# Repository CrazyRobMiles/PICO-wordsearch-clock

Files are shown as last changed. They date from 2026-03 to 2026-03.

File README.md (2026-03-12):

# PICO Wordsearch Clock

A Raspberry Pi PICO powered clock that shows the time on a 16x16 character wordsearch

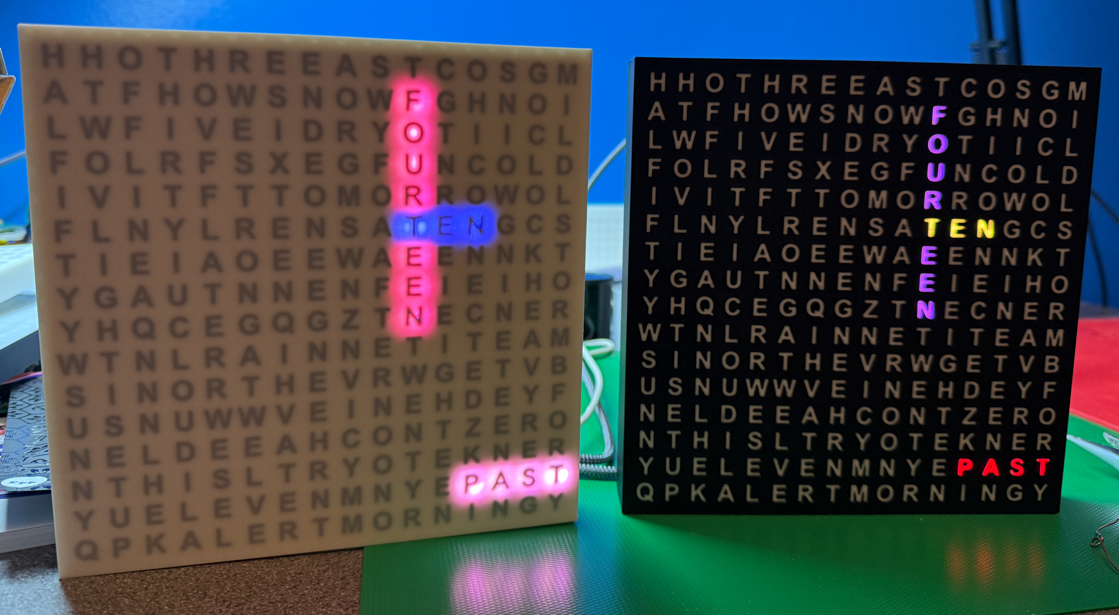
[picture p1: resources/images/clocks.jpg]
TWo wordsearch clocks, one black on white and the other white on black


There are two versions of the clock. One is an alarm clock. The same software works with both versions.

## Installing the software

**These instructions assume that you are familiar with MicroPython development for the Raspberry Pi PICO.**

The software is in the **firmware-PICO** folder. Install MicroPython on your device and then copy all the files in the **firmware-PICO** folder onto your device. You can use the Thonny program or Visual Studio Code with the Raspberry Pi plugin to do this. 

The best way to deploy the software is to use the Raspberry Pi Pico plugin for Visual Studio Code. Install the plugin and then open the **firmware-PICO** folder with Visual Studio Code **not** this repository. Plug the target PICO W into your computer, right click on any file in the file explorer and select **Upload Project to Pico** from the context menu that appears. Now you can configure the Wi-Fi. 

## Configuring the Wi-Fi

Once you have installed the software you will need to configure the Wi-Fi connection for your clock. The clock uses Wi-Fi to get the date and time. The configuration for Wi-Fi is in the **settings.json** file in the firmware folder. Use Thonny or Visual Studio Code 

```json
    "wifi": {
        "dependencies": [],
        "wifipwd1": "",
        "enabled": true,
        "retry_interval_ms": 30000,
        "wifissid1": ""
    },
```
You need to set values for **wifipwd1** and **wifissid1**. Save the file back to the device after you have edited it. Now, when your clock starts it will connect to your Wi-Fi and start displaying the time. 

### **IMPORTANT NOTE**

Your Wi-Fi settings are held in clear text inside the clock. Anyone who gains access to the clock could plug it into their computer and read the Wi-Fi settings out of it. It is good practice to create a "guest" Wi-Fi account for embedded devices so that anyone getting the credentials does not get access to all the devices on your home network. 

## Using the alarm clock

### Getting started
Plug in the clock and it should fetch the time from the internet start showing it. This will  take a few seconds to do this. The clock will not display the time until it has established a Wi-Fi connection. 

### Adjusting Brightness

Use the white buttons to adjust the brightness. One button makes the clock brighter and the other makes it darker. 

### Adjusting the alarm time

Press and hold the red button to set the alarm hour. Use the white buttons to adjust the hour value. Note that this is a 24-hour clock setting. Times after mid-day will be plus 12. In other words 2:00pm will be 14:00 hours. 

Press and hold the blue button to set the alarm minute. Use the white buttons to adjust the minute value. 

If you hold down a white button it will automatically step through the values for you. 

### Turning the alarm on and off

Press the red and blue buttons to turn the alarm on and off. The display will show yellow for off and red for the alarm on. 

### Alarm sound

If the alarm is enabled it will trigger at the set time. Press any button to cancel the alarm. 

### Alarm demonstration

To see a demonstration of the alarm display and sound, press both white buttons together. If the alarm is disabled you will hear one demo. 

# Building a clock of your own

You can find out how to build your own clock in the resources folder [here](/resources/README.md).

Have Fun!

[Rob Miles](https://www.robmiles.com/)

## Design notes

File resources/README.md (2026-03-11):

## Building a clock

You can build your own version of the clock. The simplest way to do this is to use the supplied case designs and **clockface.json** file. This will produce a clock with the wordsearch arrangement you can see above. If you want to make your own wordsearch design you can do this, but it is slightly more complex.

If you build the alarm clock you'll need to set up a MicroSD card with the sound samples to be used for the alarms. 

### Printing the case

The stl files and instructions are [here](stl/README.md).

### Building the electronics

You can find a parts list and circuit diagram [here](circuit/README.md)

### Designing your own Wordsearch

You can find out how to make your own wordsearch design [here](custom/README.md). 

## Creating your own sounds for the clock

You can find out how to create your own alarm sounds [here](sounds/README.md).

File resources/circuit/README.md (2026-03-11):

# Building the Circuit

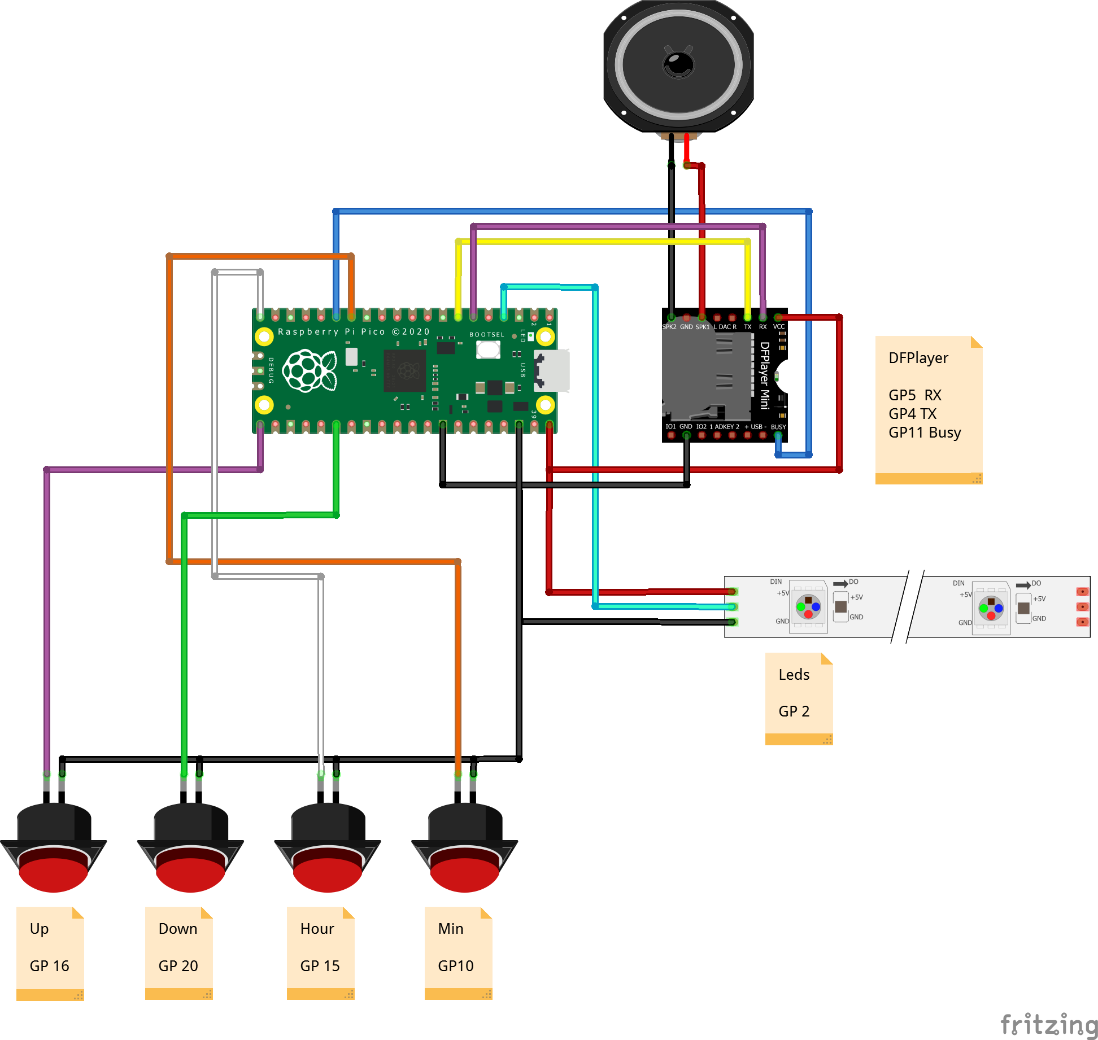
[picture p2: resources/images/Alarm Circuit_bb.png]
Circuit diagram of the clock


The diagram shows the circuit for the clock. If you are not building the alarm clock you only need these:

* Raspberry PI PICO 2 W
* 16x16 led panel with 10mm led spacing. 
* DuPont cables. The prototypes were constructed by using short DuPont male-to-male cables which were soldered into the switch connections onto the LED panel. the other male end of the cables were soldered into the PICO directly. One special cable was created which split the VBUS power connection so that the leds and the DFPlayer could be powered. 

## Alarm Clock

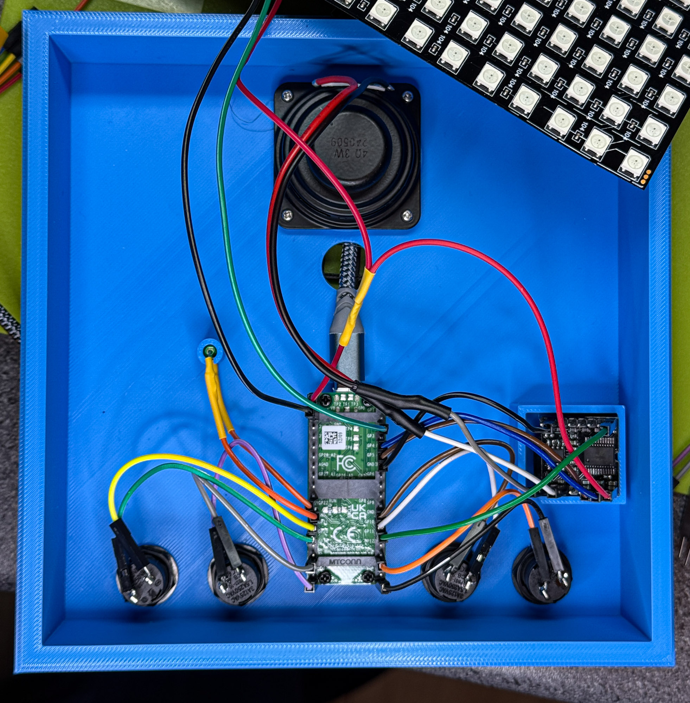
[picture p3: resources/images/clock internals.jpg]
Image of the inside of the clock showing connections


You can make a version of the clock which will sound an alarm at a set time during the day. The alarm sounds are stored on a Micro-SD card inside the clock and played by a DFPlayer device controlled by the PICO. The alarm clock uses four buttons to set the alarm. You need these extra components:

* DFPlayer - search for "DFPlayer Mini mp3" 
* Micro-SD card – between 4Gbytes and 16Gbytes work well
* Four non-latching push buttons which fit in a 13mm diameter hole
* 40mm speaker with mounting holes spaced at 32.5mm

## Design Changes

You can modify the FreeCAD program that creates the case if you wish to use differently sized components.  You can modify the **settings.json** file for the device if you want to use different pin assignments in your circuit.

[Resources Home](../README.md)

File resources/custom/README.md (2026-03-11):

# Custom Wordsearch Design

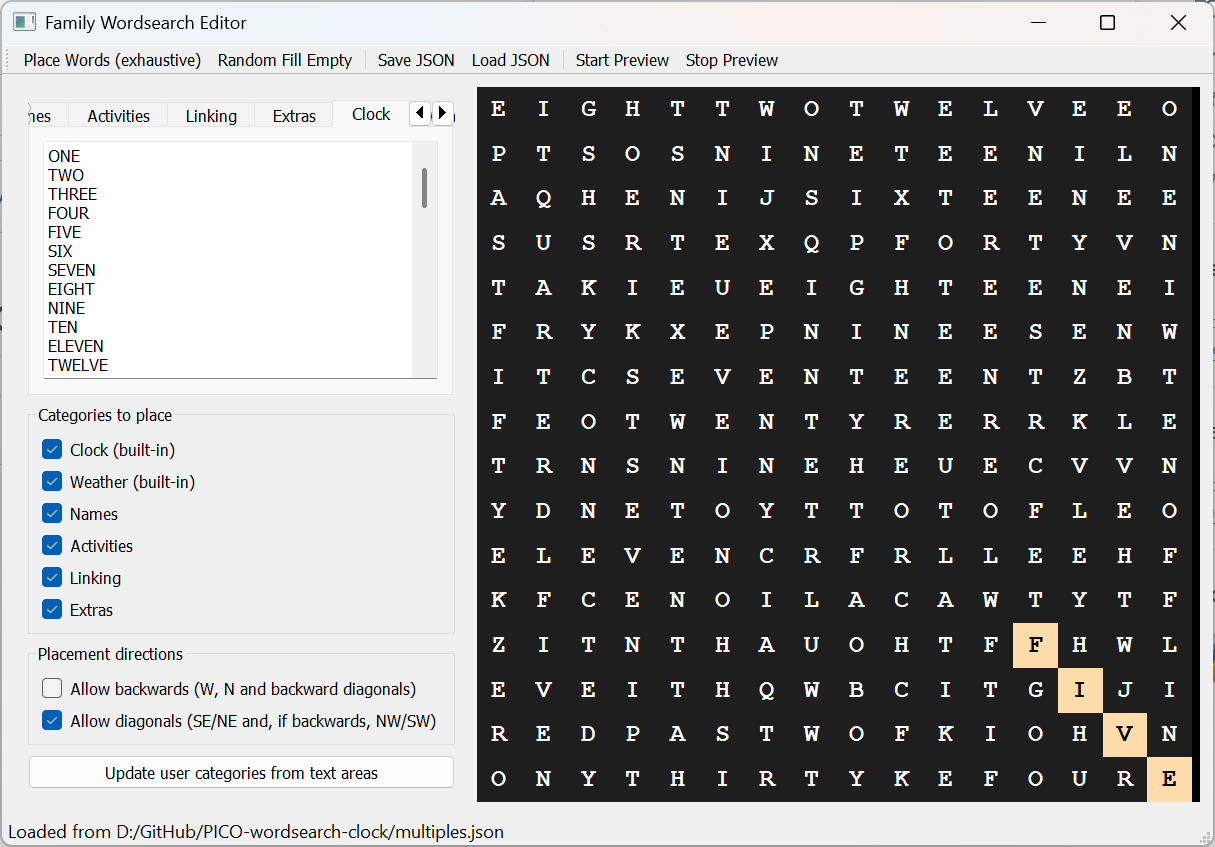
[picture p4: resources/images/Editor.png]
Python editor showing a wordsearch being edited


If you want to create your own wordsearch design you can use the Python **WordsearchEditor** program. Installers are provided for Raspberry Pi, Windows and Mac systems.

The program will build a wordsearch containing different sets of words. You can add to the sets of words although the present version of clock does not use them. The prorogram will make multiple attempts to create the wordsearch before giving up. If it repeatedly fails you will have to reduce the number of words you are using. You can load the existing wordsearch design (in the file **clockface.json**) as a starting point.

You put your custom wordsearch file in the firmware folder, replacing the existing **clockface.json** file. 

The customer wordsearch design file is used by the FreeCAD design program to create the STL files for printing your custom clock. Load the **Builder.py** program into the [FreeCAD](https://www.freecad.org/index.php?lang=en) design tool. Direct the program to your json clock file by editing this line at the top of program:

```Python
json_path = r"D:\GitHub\PICO-wordsearch-clock\firmware-PICO\clockface.json"
```

Now you can run the program to create the case files for your custom wordsearch. You select the format you want by un-commenting one of the statements which are at the bottom of the **Builder.py** source file. 

```Python
# design for through hole letters
#make_grid(grid=rows,engrave_letters=True,no_letters_on_tiles=False,letter_cell_base_thickness_mm=2.0,letter_thickness_mm=2.0,behind_letter_panel_thickness=0.5)

# design for obscured letters
#make_grid(grid=rows,engrave_letters=True,no_letters_on_tiles=False)

# Test design for making quick boxes to check layout
make_grid(grid=rows,engrave_letters=True,no_letters_on_tiles=True,letter_cell_base_thickness_mm=2.0,letter_thickness_mm=2.0,behind_letter_panel_thickness=0.5,speaker=True)
```
[Resources Home](../README.md)

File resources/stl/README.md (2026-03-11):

# Case Build Files

This folder contains all the build files for the clock. You can print them in standard PLA 

## Front Panel Design

The front of the clock is made from two elements which are printed as one, using a printer which supports multiple filaments. The panel element contains voids that are filled with the letters. One of the two elements should be transparent so that lights behind the letters can shine through.

A picture of the front panel with black text inside it

There are two versions of the front panel and letters. One has a smooth front surface with the letters slightly behind it.  The other has letters which are printed all the way through the front panel. You can see the two different designs above. Pick the front design that you prefer from the folder **Obscured Letters** or the folder **Through Letters**. If you use the one with a smooth front surface be careful not to use a strong colour for it as the letters might not be visible.

When you slice the front panel design you need to drag both **frontLetters** and **frontPanel** into the slicer and then say yes to the dialogue that appears. 

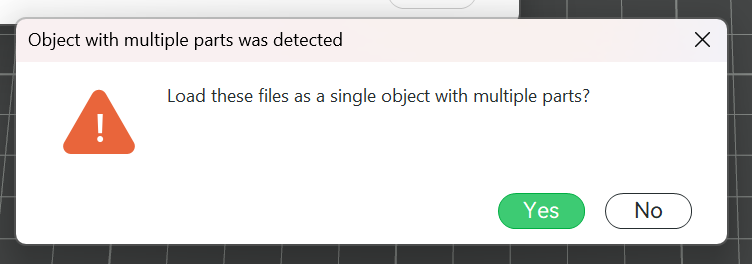
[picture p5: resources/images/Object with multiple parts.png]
Bambu Slicer object with multiple parts import dialogue


You can now use the slicer menu to select different colours for the two objects. If you use the **Through Letters** design you should slow the printer down for the first few layers of the print. This is to make sure that the individual letters (which are usually printed first) adhere to the bed.

## Case Parts

The other parts of the clock are common to both designs. The **separator** fits between the front of the clock and the flexible LED panel and reduces the light bleed from one letter to another. This should be printed using an opaque colour, preferably black.

The are two back files, one contains fittings for the alarm control buttons, DFPlayer device and speaker. The other is for use with the standard clock configuration. None of the files needs support when printed. The front and the back of the clock snap together. 

[Resources Home](../README.md)

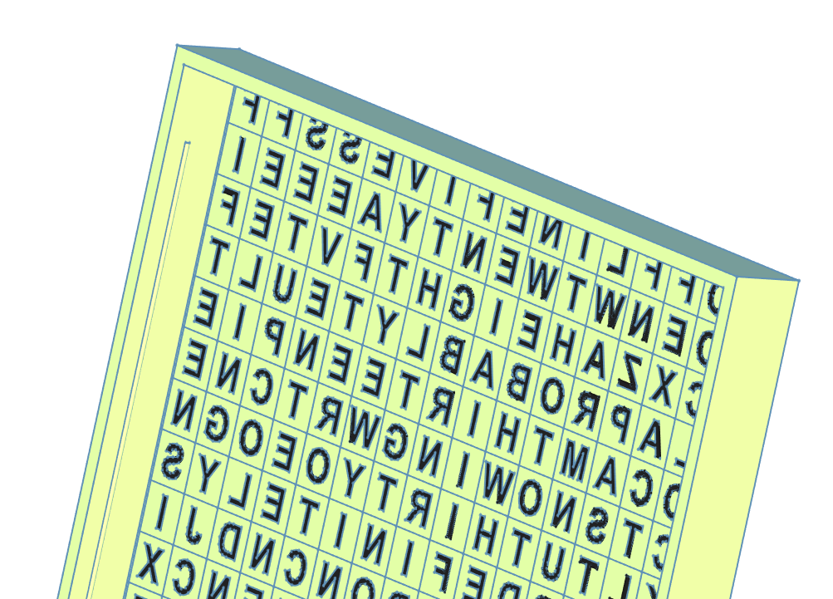
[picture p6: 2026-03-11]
resources/images/panel and text.png

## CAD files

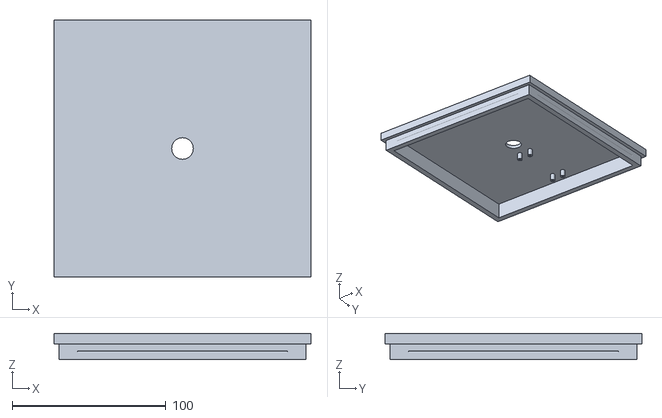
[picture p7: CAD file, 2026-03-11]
resources/stl/back.stl
167.0 x 167.0 x 17.0

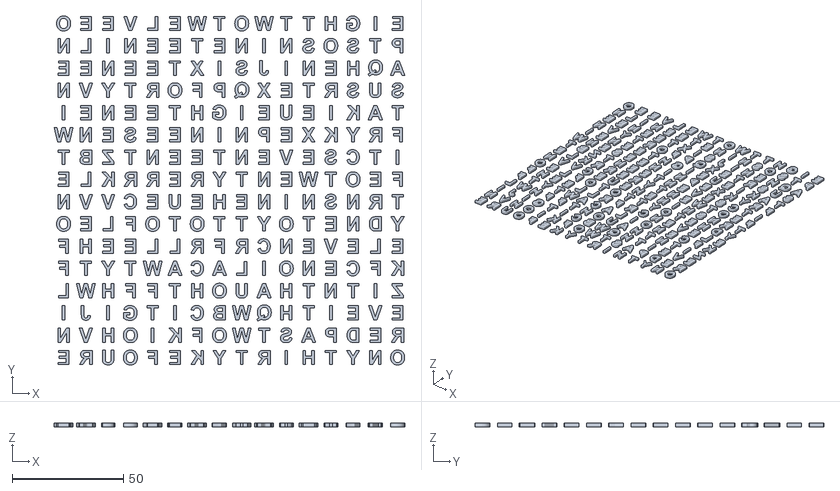
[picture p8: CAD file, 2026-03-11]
resources/stl/Obscured Letters/frontLetters.stl
157.5 x 156.7 x 1.60

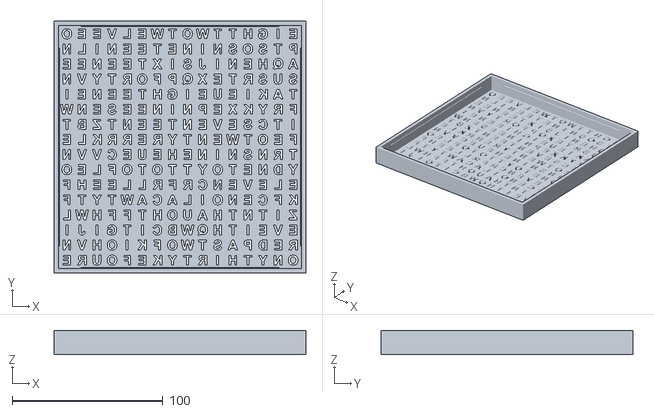
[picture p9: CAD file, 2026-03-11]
resources/stl/Through Letters/frontPanel.stl
167.0 x 167.0 x 16.2

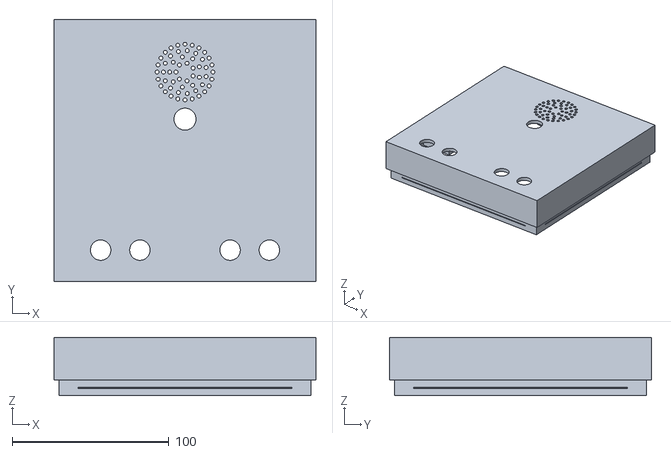
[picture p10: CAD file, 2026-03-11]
resources/stl/alarmBack.stl
167.0 x 167.0 x 37.0

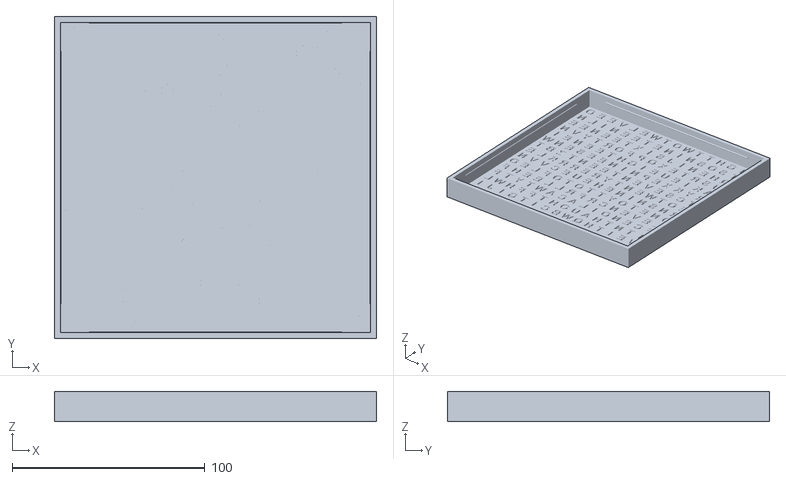
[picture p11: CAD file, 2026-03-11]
resources/stl/Obscured Letters/frontPanel.stl
167.0 x 167.0 x 15.7

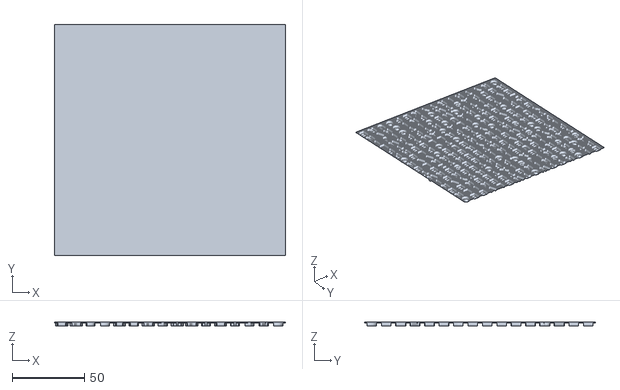
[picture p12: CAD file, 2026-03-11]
resources/stl/Through Letters/frontLetters.stl
160.0 x 160.0 x 2.50

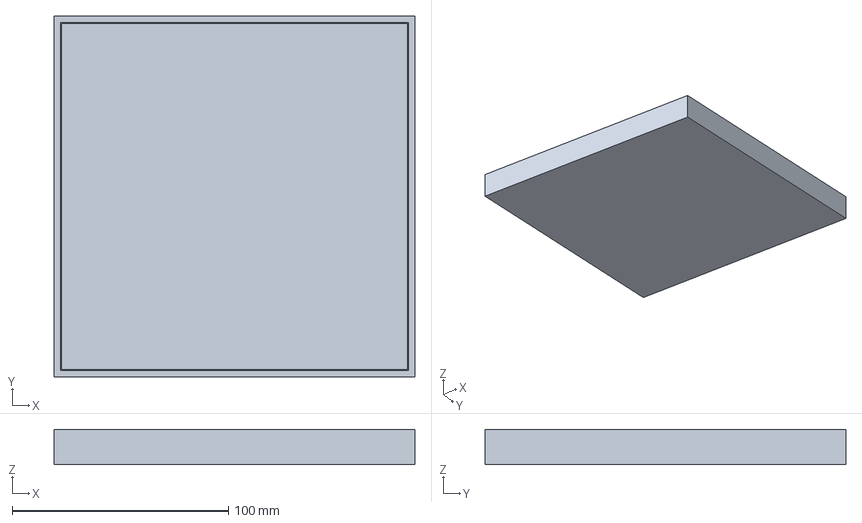
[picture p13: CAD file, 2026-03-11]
resources/stl/Black Background.3mf
167.0 x 167.0 x 16.2 mm

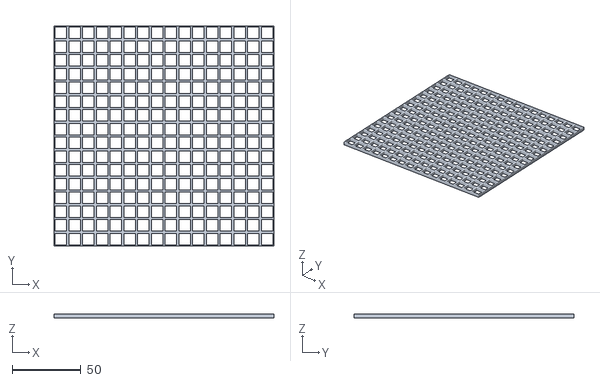
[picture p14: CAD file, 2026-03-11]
resources/stl/separator.stl
160.0 x 160.0 x 3.00

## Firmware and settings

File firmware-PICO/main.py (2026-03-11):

version = "1.0.4"

from device_configurator import DeviceConfigurator

from clb import CLB

debug=True

config = DeviceConfigurator(
    settings_file="settings.json",
    safe_pin=-1,
    use_obfuscation=False
)

if not config.setup(force_online=False):
    config.setup(force_online=True)

clb = CLB(config)

clb.setup()

clb.describe()

if debug:
    while clb.running:
        clb.update()
        clb.update_console()
else:
    try:
        while clb.running:
            clb.update()
            clb.update_console()
    except Exception as e:
        print(e)
        clb.teardown()
 
 

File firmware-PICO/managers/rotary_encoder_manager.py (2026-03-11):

from managers.base_manager import CLBManager
from managers.event import Event
import machine
import time


class Manager(CLBManager):
    version = "1.0.0"

    def __init__(self, clb):
        super().__init__(clb, defaults={
            "encoders": []
        })
        self.encoders = {}  # {encoder_name: EncoderHandler}
        self.events = {}    # {event_name: Event object}

    def setup(self, settings):
        super().setup(settings)

        if not self.enabled:
            self.state = self.STATE_DISABLED
            return

        self.state = self.STATE_OK
        self.set_status(6101, "Rotary encoder manager ready")

    def setup_services(self):
        """Called after all managers are set up. Connect to event manager."""
        # Configure encoders from settings
        encoders_config = self.settings.get("encoders", [])
        for encoder_config in encoders_config:
            self._configure_encoder(encoder_config)

    def _configure_encoder(self, encoder_config):
        """Configure a rotary encoder from a config dict"""
        if not isinstance(encoder_config, dict):
            print(f"[RotaryEncoder] Invalid encoder config: {encoder_config}")
            return

        encoder_name = encoder_config.get("name")
        clk_pin = encoder_config.get("clk_pin")
        dt_pin = encoder_config.get("dt_pin")
        btn_pin = encoder_config.get("btn_pin")

        if not encoder_name or clk_pin is None or dt_pin is None:
            print(f"[RotaryEncoder] Encoder config missing name, clk_pin, or dt_pin")
            return

        try:
            encoder = EncoderHandler(
                name=encoder_name,
                clk_pin=clk_pin,
                dt_pin=dt_pin,
                btn_pin=btn_pin,
                manager=self
            )
            self.encoders[encoder_name] = encoder
            self._create_encoder_events(encoder_name)
            print(f"[RotaryEncoder] Configured encoder '{encoder_name}' (CLK: {clk_pin}, DT: {dt_pin}, BTN: {btn_pin})")
        except Exception as e:
            print(f"[RotaryEncoder] Failed to configure encoder '{encoder_name}': {e}")

    def _create_encoder_events(self, encoder_name):
        """Create events for a specific encoder"""
        event_names = [
            f"rotary_encoder.{encoder_name}_connected",
            f"rotary_encoder.{encoder_name}_moved_clockwise",
            f"rotary_encoder.{encoder_name}_moved_anticlockwise",
            f"rotary_encoder.{encoder_name}_button_pressed"
        ]

        for event_name in event_names:
            if event_name not in self.events:
                self.events[event_name] = Event(
                    name=event_name,
                    description=f"Rotary encoder '{encoder_name}' event: {event_name.split('_', 1)[1]}",
                    owner=self
                )

    def get_event(self, event_name):
        """Get an event object by name for subscription"""
        return self.events.get(event_name)

    def publish_event(self, event_name, data=None):
        """Publish an event with data"""
        if event_name in self.events:
            self.events[event_name].publish(data)

    def update(self):
        """Called on each manager update cycle to poll encoder inputs"""
        if not self.enabled or self.state != self.STATE_OK:
            return

        # Update each encoder
        for encoder_name, encoder in self.encoders.items():
            encoder.update(self)

    def get_interface(self):
        """Return exposed commands"""
        return {
            "list": ("list", self.command_list_encoders),
            "status": ("status <name>", self.command_encoder_status),
        }

    def command_list_encoders(self):
        """List all configured encoders"""
        if not self.encoders:
            print("[RotaryEncoder] No encoders configured")
            return

        for encoder_name in self.encoders:
            print(f"  - {encoder_name}")

    def command_encoder_status(self, encoder_name=""):
        """Get status of a specific encoder"""
        if not encoder_name:
            print("[RotaryEncoder] Please provide encoder name")
            return

        encoder = self.encoders.get(encoder_name)
        if not encoder:
            print(f"[RotaryEncoder] Encoder '{encoder_name}' not found")
            return

        print(f"[RotaryEncoder] {encoder_name}:")
        print(f"  CLK Pin: {encoder.clk_pin}")
        print(f"  DT Pin: {encoder.dt_pin}")
        print(f"  Button Pin: {encoder.btn_pin}")
        print(f"  Last CLK State: {encoder.last_clk_state}")
        print(f"  Last DT State: {encoder.last_dt_state}")
        print(f"  Last Button State: {encoder.last_btn_state}")

    def teardown(self):
        """Clean up encoder resources"""
        for encoder_name, encoder in self.encoders.items():
            encoder.cleanup()
        self.set_status(6102, "Rotary encoder manager torn down")
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

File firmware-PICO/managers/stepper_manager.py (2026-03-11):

from managers.base_manager import CLBManager
import machine, math, time, sys

# NEW: cross-platform hardware abstraction layer
import compat
from compat import (
    start_periodic_timer,
    cancel_timer,
    monotonic_us,
)

# ======== CROSS-PLATFORM, TIMER-DRIVEN STEPPER MANAGER ========

class Manager(CLBManager):
    """
    Drives 1–4 x 28BYJ-48 steppers via ULN2003 (4 pins each) using an 8-step half-step sequence.
    - Uses compat.py to support both Pico (rp2) and ESP32 reliably.
    - High-resolution timers on Pico, safe ms timers on ESP32.
    - Public API: move(mm), rotate(deg), arc(radius, deg) + console commands.
    """

    version = "1.3.1"

    STATE_DISABLED = "disabled"
    STATE_READY    = "ready"
    STATE_ERROR    = "error"
    STATE_MOVING   = "moving"

    # 8-step half-step sequence (IN1..IN4)
    HALFSTEP = (
        (1,0,0,0),
        (1,1,0,0),
        (0,1,0,0),
        (0,1,1,0),
        (0,0,1,0),
        (0,0,1,1),
        (0,0,0,1),
        (1,0,0,1),
    )

    def __init__(self, clb):
        super().__init__(clb, defaults={
            # Up to four motors; -1 pins mean “unused motor”
            "motors": [
                {"pins":[-1,-1,-1,-1], "wheel_diameter_mm":69.0},  # motor 0: left
                {"pins":[-1,-1,-1,-1], "wheel_diameter_mm":69.0},  # motor 1: right
                {"pins":[-1,-1,-1,-1], "wheel_diameter_mm":69.0},  # optional
                {"pins":[-1,-1,-1,-1], "wheel_diameter_mm":69.0},  # optional
            ],
            "wheel_spacing_mm": 110.0,      # centre-to-centre distance
            "steps_per_rev":    4096,       # half-step count for 28BYJ-48
            "min_step_delay_us": 1200,      # fastest step interval
            "enabled":          False
        })
        self._m = []          # runtime motor data
        self._timer = None
        self._tick_us = 200    # target tick (compat adjusts on ESP32)
        self._moving_any = False
        self._last_interval_us = int(self.defaults["min_step_delay_us"])

    # ---------- Lifecycle ----------

    def setup(self, settings):
        super().setup(settings)

        if not self.enabled:
            self.state = self.STATE_DISABLED
            return

        try:
            self._build_motors()
            self._start_timer()

            self.state = self.STATE_READY
            self.set_status(7100,
                f"Stepper ready ({len(self._m)} motor(s)) on {compat.platform_name()}"
            )

        except Exception as e:
            self.state = self.STATE_ERROR
            sys.print_exception(e)
            self.set_status(7101, f"Stepper init error: {e}")

    def teardown(self):
        cancel_timer(self._timer)
        self._timer = None

        # Disable coils
        for m in self._m:
            p1,p2,p3,p4 = m["pins"]
            p1.value(0); p2.value(0); p3.value(0); p4.value(0)

        self._m.clear()
        self._moving_any = False
        self.set_status(7112, "Stepper manager torn down")

    # ---------- Internal motor setup ----------

    def _build_motors(self):
        self._m = []
        min_delay = int(self.settings["min_step_delay_us"])

        for idx, cfg in enumerate(self.settings.get("motors", [])[:4]):
            pins = cfg.get("pins", [])

            # Skip inactive motors
            if len(pins) != 4 or any(p < 0 for p in pins):
                continue

            # ESP32-safe pin creation
            pin_objs = [machine.Pin(p, machine.Pin.OUT) for p in pins]
            for p in pin_objs:
                p.value(0)

            self._m.append({
                "index": idx,
                "pins": pin_objs,
                "seq": 0,
                "dir": 1,
                "remain": 0,
                "delay": min_delay,
                "next": monotonic_us(),
                "wheel_diam": float(cfg.get("wheel_diameter_mm", 69.0)),
            })

    def _start_timer(self):
        # compat.start_periodic_timer chooses the correct timer mode per board
        self._timer = start_periodic_timer(self._irq_stepper, self._tick_us)

    # ---------- Timer callback (ISR-safe) ----------

    def _irq_stepper(self):
        now = monotonic_us()
        moving = False
        seq_len = 8
        half = self.HALFSTEP

        for m in self._m:
            if m["remain"] == 0:
                continue

            if time.ticks_diff(now, m["next"]) >= 0:
                # Update sequence
                m["seq"] = (m["seq"] + (1 if m["dir"] > 0 else -1)) % seq_len
                a,b,c,d = half[m["seq"]]
                p1,p2,p3,p4 = m["pins"]

                # Coil drive
                p1.value(a); p2.value(b); p3.value(c); p4.value(d)

                # Count down
                m["remain"] -= 1
                m["next"] = time.ticks_add(now, m["delay"])

            moving = moving or (m["remain"] != 0)

        self._moving_any = moving

    # ---------- Motion planning ----------

    def _motor(self, idx):
        for m in self._m:
            if m["index"] == idx:
                return m
        return None

    def _circ(self, m): return math.pi * m["wheel_diam"]

    def _mm_to_steps(self, m, mm):
        revs = mm / self._circ(m)
        return int(round(revs * int(self.settings["steps_per_rev"])))

    def _apply_time_pair(self, left_mm, right_mm, seconds=None):
        """Compute step interval based on motion time or use min_step_delay."""
        if seconds is None:
            interval = int(self.settings["min_step_delay_us"])
        else:
            L = self._motor(0)
            R = self._motor(1)
            steps_L = abs(self._mm_to_steps(L, left_mm)) if L else 0
            steps_R = abs(self._mm_to_steps(R, right_mm)) if R else 0
            steps = max(steps_L, steps_R)

            if steps <= 1 or seconds <= 0:
                interval = int(self.settings["min_step_delay_us"])
            else:
                requested = int((seconds * 1_000_000) / steps)
                interval = max(requested, int(self.settings["min_step_delay_us"]))

        irq = machine.disable_irq()
        try:
            for m in self._m:
                m["delay"] = interval
        finally:
            machine.enable_irq(irq)

        self._last_interval_us = interval

    def _queue_motor_mm(self, idx, distance_mm):
        m = self._motor(idx)
        if not m:
            return

        steps_signed = self._mm_to_steps(m, distance_mm)
        irq = machine.disable_irq()
        try:
            m["dir"] = 1 if steps_signed >= 0 else -1
            m["remain"] = abs(steps_signed)
            m["next"] = monotonic_us()
        finally:
            machine.enable_irq(irq)

    # ---------- Public API ----------

    def move(self, distance_mm, seconds=None):
        self._queue_motor_mm(0, distance_mm)
        self._queue_motor_mm(1, distance_mm)
        self._apply_time_pair(distance_mm, distance_mm, seconds)
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
